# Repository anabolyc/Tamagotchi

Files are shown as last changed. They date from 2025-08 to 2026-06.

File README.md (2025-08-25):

# ArduinoGotchi - A real Tamagotchi emulator for Arduino UNO

## Synopsis

**ArduinoGotchi** is a real [Tamagotchi P1](https://tamagotchi.fandom.com/wiki/Tamagotchi_(1996_Pet)) emulator running in Arduino UNO hardware. The emulation core is based on [TamaLib](https://github.com/jcrona/tamalib) with intensive optimization to make it fit into UNO's hardware that only comes with 32K Flash 2K RAM.

Tamagotchi P1 Actual Devices

## Fork notice

I did the following changes after forking [original repo](https://github.com/GaryZ88/ArduinoGotchi)
- Created a platformio project, so it is easy to target multiple platforms
- Created ports for ESP8266 and ESP32, mainly because the speed on 8-bit AVR is just too slow
- Added long click on "back" button - if you press it for 5 seconds, it will reset memory back to egg state
- Added inverted Speaker connection setting. Mainly because the Piezo modules that I have are active on Low. Another reason is mentioned below.

I personally assembled the ESP8266 version with Wemos D1 Mini on a perf board, using the built-in LED together with a speaker, so when it sounds, the LED is blinking as well.

### Demo
Demo #1
Demo #2
Demo #3

## How to build and run

Use Platformio. Run the `build` task to build for all platforms. Next, run the `Upload` task for a specific platform

### Additional notes
- To activate your pet, you have to configure the clock by pressing the middle button. Otherwise, your pet will not be alive.
- The emulator will save the game status every 5 minutes. You can change that by changing the AUTO_SAVE_MINUTES setting
- The speed of the emulator is a bit slower than the actual Tamagotchi device on AVR; still, it is fun. On ESPs, it runs smoothly.
- There are a few costs in the `platformio.ini` that you can adjust to fit your needs:
```
  -D DISPLAY_I2C_ADDRESS=0x3C
  -D SCREEN_WIDTH=128
  -D SCREEN_HEIGHT=64
  -D ENABLE_TAMA_SOUND
  -D ENABLE_TAMA_SOUND_ACTIVE_LOW
  -D ENABLE_AUTO_SAVE_STATUS
  -D ENABLE_LOAD_STATE_FROM_EEPROM
```

### Board revisions

#### Revision A

The first prototype used an external boost converter module soldered on the PCB for simplicity. However boost converter I used would give up too early, not pulling all the juice from the battery.
This version contained one schematic issue: GPIO2 used for the buzzer caused boot issues (bootstrap pin)



#### Revision B

Switched over to on-board boost converter (TPS61040DBVR). Buzzer pin changed to IO0.



#### Revision C

Identical electrically to rev B, however, I switched to onboard SMD buttons (soldered from the factory), as they had much better feel compared to the through-hole buttons I used before. 



#### Revision D

Switched to XC9140A331MR boost converter, as this one can run down to 0.9V before it dies out. Added onboard power switch, so it can be switched off without removing batteries. Switched to onboard buzzer I used in another project to make the bottom line flat (that way it can be placed on the desk, for example). 

Also, I decided to switch to ESP32-S2 from ESP8266 as they become more and more available. Also I had a bunch of them, and I didn't really know where to use them ;)



### License
ArduinoGotchi is distributed under the GPLv2 license. See the LICENSE file for more information.

### Where to buy

You may support my work by ordering the kit on [Tindie](https://www.tindie.com/products/sonocotta/esp8266-tamagotchi-diy-kit/) or [Elecrow](https://www.elecrow.com/esp8266-tamagotchi-diy-kit.html)

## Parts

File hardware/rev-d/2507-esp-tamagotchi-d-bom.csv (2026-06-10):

ID | Name | Designator | Footprint | Quantity | Manufacturer Part | Manufacturer | Supplier | Supplier Part | Price
1 | BH-AAA-B5AK001 | BT1 | BAT-SMD_BH-AAA-B5AA001 | 1 | BH-AAA-B5AK001 | MYOUNG(美阳) | LCSC | C964882 | 1.188
2 | SSSS811101 | SW5 | SW-SMD_SSSS811101 | 1 | SSSS811101 | ALPSALPINE(阿尔卑斯阿尔派) | LCSC | C109335 | 0.147
3 | 2700Hz | BUZZER2 | BUZ-SMD_4P-L8.5-W8.5-P8.50-BR | 1 | MLT-8530 | 华能 | LCSC | C94599 | 0.208
4 | 10uF | C3,C10 | C0805 | 2 | CL21A106KAYNNNE | SAMSUNG | LCSC | C15850 | 0.048
5 | 4.7uH | L1 | IND-SMD_L4.0-W4.0 | 1 | YNR4018-4R7M | YJYCOIN(益嘉源) | LCSC | C340369 | 0.066
6 | 100nF | C13,C12 | C0402 | 2 | CL05B104KO5NNNC | SAMSUNG | LCSC | C1525 | 0.002
7 | 10uF | C15,C16 | CAP-SMD_L3.2-W1.6-RD-C7171 | 2 | TAJA106K016RNJ | Kyocera AVX | LCSC | C7171 | 0.15
8 | XC9140A331MR-G | U6 | SOT-23-5_L2.9-W1.6-P0.94-LS2.8-BL | 1 | XC9140A331MR-G | TOREX(特瑞仕) | LCSC | C484298 | 0.644
9 | MIDDLE | SW1 | KEY-SMD_2P-L6.0-W6.0-P6.00 | 1 | SKPMBJE010 | ALPSALPINE(阿尔卑斯阿尔派) | LCSC | C842853 | 0.162
10 | RIGHT | SW2 | KEY-SMD_2P-L6.0-W6.0-P6.00 | 1 | SKPMBJE010 | ALPSALPINE(阿尔卑斯阿尔派) | LCSC | C842853 | 0.162
11 | LEFT | SW3 | KEY-SMD_2P-L6.0-W6.0-P6.00 | 1 | SKPMBJE010 | ALPSALPINE(阿尔卑斯阿尔派) | LCSC | C842853 | 0.162
12 | 10kΩ | R6,R7,R8 | R0805 | 3 | 0805W8F1002T5E | UNI-ROYAL(厚声) | LCSC | C17414 | 0.003

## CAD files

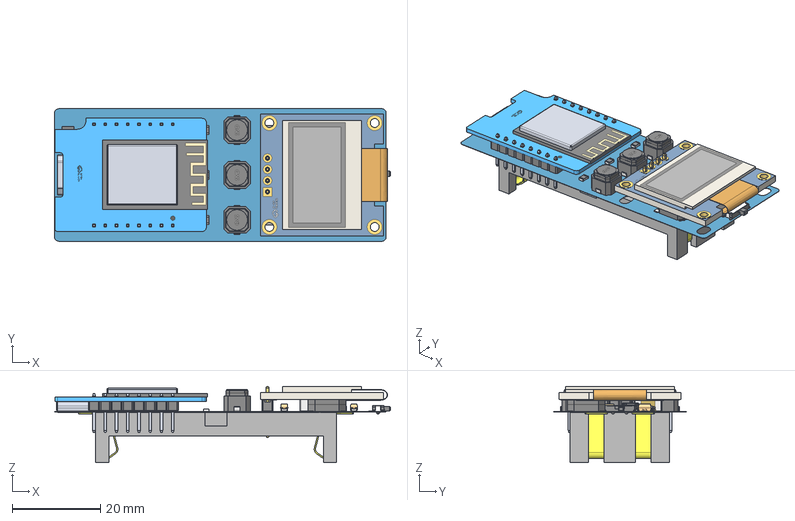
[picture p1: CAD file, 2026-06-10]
hardware/rev-d/2304-esp-tamagotchi-d-step.step
75.9 x 30.0 x 17.2 mm
Board~Su5C
TopCopper~Su5C
BottomCopper~Su5C
TopSilkscreen~Su5C
BottomSilkscreen~Su5C
TopFpcStiffener~Su5C
BottomFpcStiffener~Su5C
C0805~C0805_L2.0-W1.3-H1.3~YBXs x 2
C0402~C0402_L1.0-W0.5-H0.5~pOAQ x 2
IND-SMD_L4.0-W4.0~IND-SMD_L4.0-W4.0-H1.9~UKnZ
CAP-SMD_L3.2-W1.6-RD-C7171~CASE-A_L3.2-W1.6-H1.6~hhSS x 2
BUZ-SMD_4P-L8.5-W8.5-P8.50-BR~BUZ-SMD_4P-L8.5-W8.5-H4.0~ux79
SW-SMD_SSSS811101~SW-TH_SSSS811101~p5gn
R0805~R0805_L2.0-W1.3-H0.6~nQuS x 3
BAT-SMD_BH-AAA-B5AA001~BAT-SMD_BH-AAA-B5AA001~pLz2
KEY-SMD_2P-L6.0-W6.0-P6.00~KEY-SMD_2P-L6.0-W6.0-H5.0-P6.00~R7So x 3
SOT-23-5_L2.9-W1.6-P0.94-LS2.8-BL~SOT-23-5_L2.9-W1.6-P0.94-LS2.8-BL~vnJl
WEMOS D1 MINI~DIP-16_WEMOS_D1_MINI_PRO4~re9i
0.96-OLED-DISPLAY~TH-4_SSD1306~hwig

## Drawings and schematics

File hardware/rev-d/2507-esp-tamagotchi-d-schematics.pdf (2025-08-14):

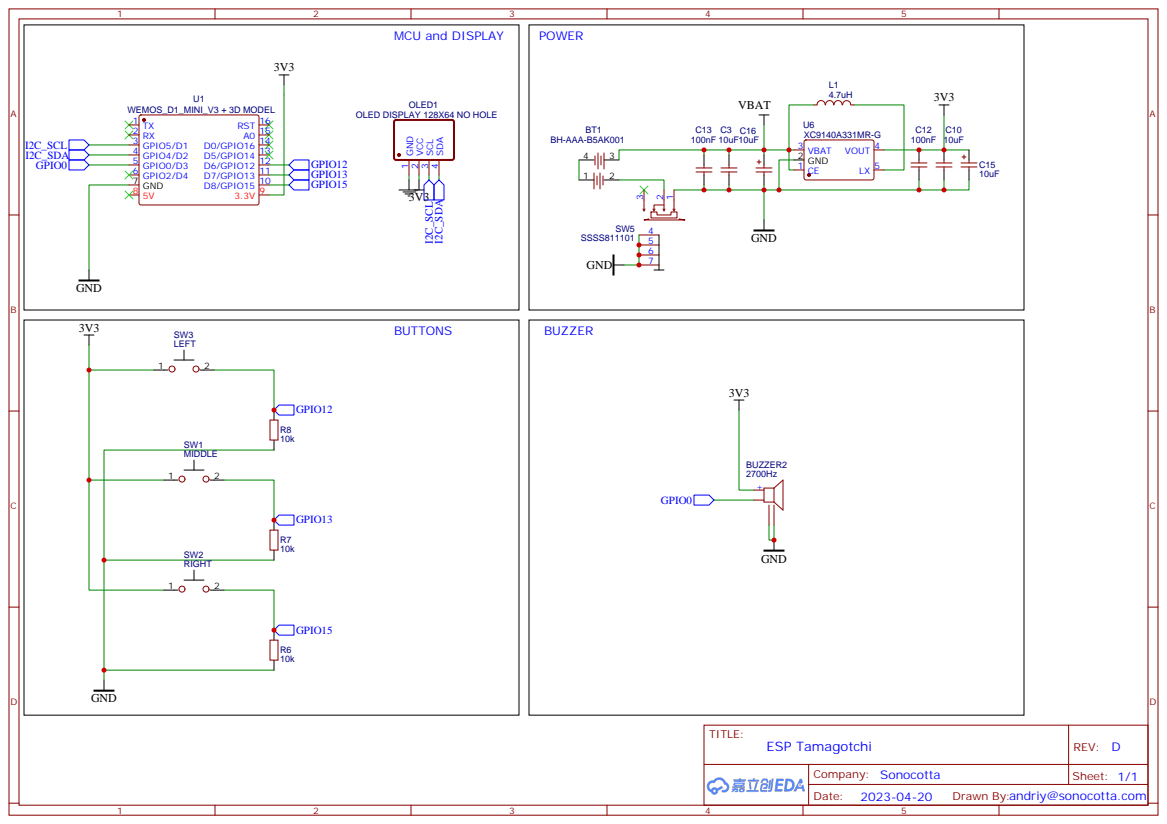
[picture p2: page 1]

OLED DISPLAY 128X64 NO HOLE

Drawn By:andriy@sonocotta.com

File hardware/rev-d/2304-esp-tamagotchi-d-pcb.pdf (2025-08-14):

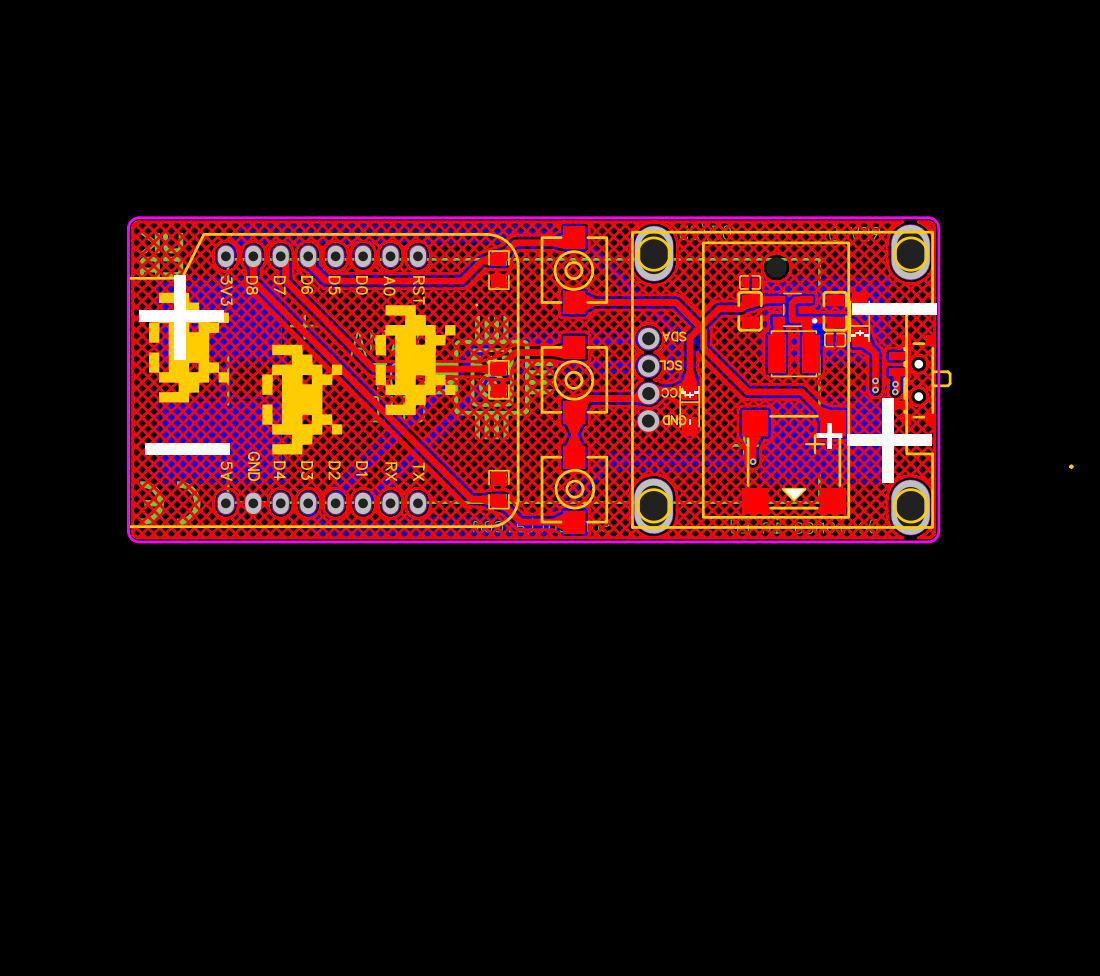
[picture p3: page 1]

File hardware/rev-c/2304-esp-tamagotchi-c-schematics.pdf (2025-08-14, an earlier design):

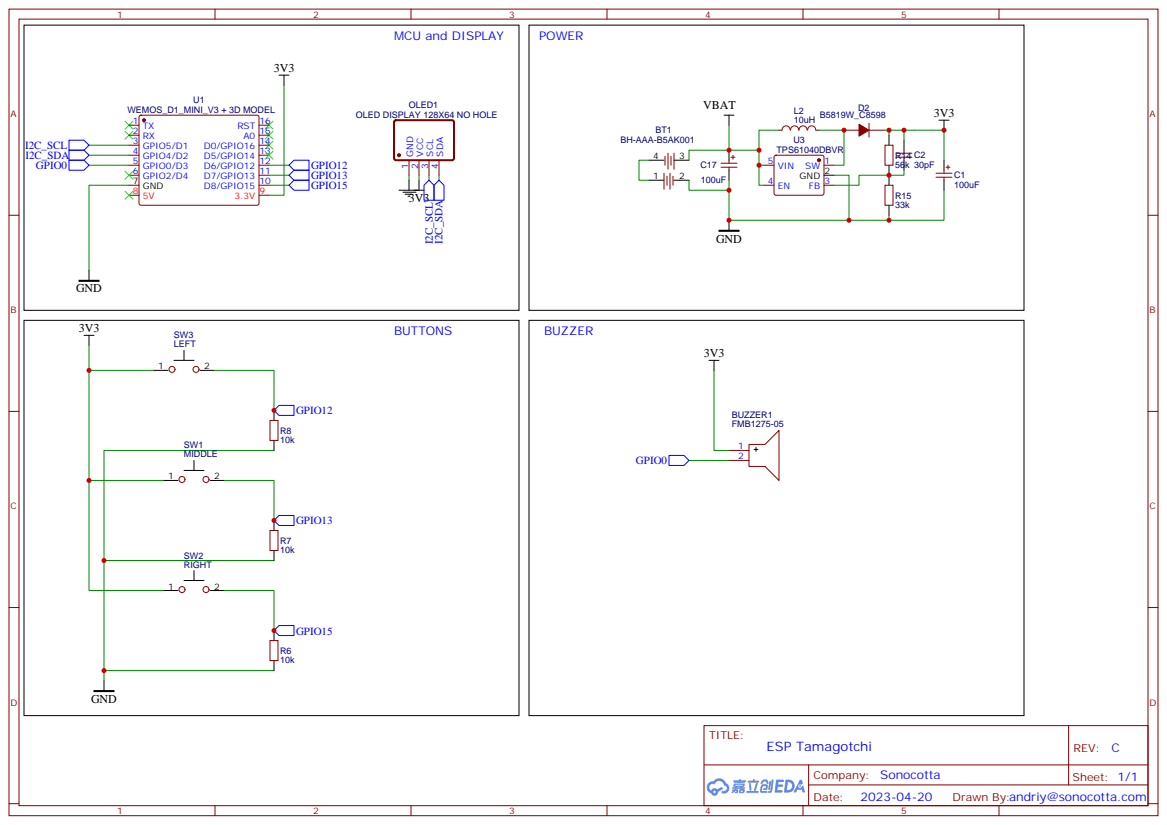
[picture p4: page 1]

OLED DISPLAY 128X64 NO HOLE

Drawn By:andriy@sonocotta.com

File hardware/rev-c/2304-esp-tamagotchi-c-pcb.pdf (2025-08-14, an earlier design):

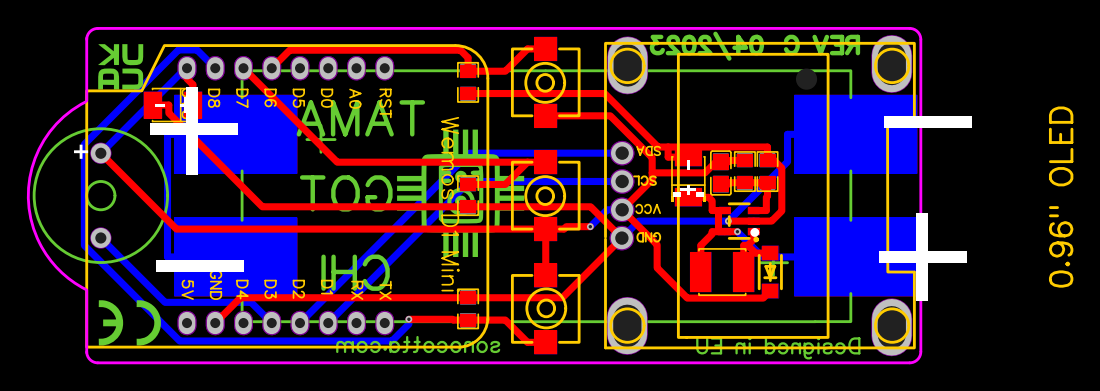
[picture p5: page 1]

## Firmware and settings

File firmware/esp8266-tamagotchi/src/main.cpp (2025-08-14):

/*
 * ArduinoGotchi - A real Tamagotchi emulator for Arduino UNO
 *
 * Copyright (C) 2022 Gary Kwok
 *
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
 * You should have received a copy of the GNU General Public License
 * along with this program; if not, write to the Free Software
 * Foundation, Inc., 51 Franklin Street, Fifth Floor, Boston, MA  02110-1301, USA.
 */

#include <U8g2lib.h>
#include <Wire.h>

#include "tamalib.h"
#include "hw.h"
#include "bitmaps.h"
#include "savestate.h"

/***** Set display orientation, U8G2_MIRROR_VERTICAL is not supported *****/
//#define U8G2_LAYOUT_NORMAL
#define U8G2_LAYOUT_ROTATE_180
//#define U8G2_LAYOUT_MIRROR
/**************************************************************************/

#if defined(PIN_I2C_SDA) && defined(PIN_I2C_SCL) 
#ifdef U8G2_LAYOUT_NORMAL
U8G2_SSD1306_128X64_NONAME_2_HW_I2C display(U8G2_R0, U8X8_PIN_NONE, PIN_I2C_SCL, PIN_I2C_SDA);
#endif
#ifdef U8G2_LAYOUT_ROTATE_180
U8G2_SSD1306_128X64_NONAME_2_HW_I2C display(U8G2_R2, U8X8_PIN_NONE, PIN_I2C_SCL, PIN_I2C_SDA);
#endif
#ifdef U8G2_LAYOUT_MIRROR
U8G2_SSD1306_128X64_NONAME_2_HW_I2C display(U8G2_MIRROR, U8X8_PIN_NONE, PIN_I2C_SCL, PIN_I2C_SDA);
#endif
#else
#ifdef U8G2_LAYOUT_NORMAL
U8G2_SSD1306_128X64_NONAME_2_HW_I2C display(U8G2_R0);
#endif
#ifdef U8G2_LAYOUT_ROTATE_180
U8G2_SSD1306_128X64_NONAME_2_HW_I2C display(U8G2_R2);
#endif
#ifdef U8G2_LAYOUT_MIRROR
U8G2_SSD1306_128X64_NONAME_2_HW_I2C display(U8G2_MIRROR);
#endif
#endif

void displayTama();

/**** TamaLib Specific Variables ****/
static uint16_t current_freq = 0;
static bool_t matrix_buffer[LCD_HEIGHT][LCD_WIDTH / 8] = {{0}};
//static byte runOnceBool = 0;
static bool_t icon_buffer[ICON_NUM] = {0};
static cpu_state_t cpuState;
static unsigned long lastSaveTimestamp = 0;
/************************************/

static void hal_halt(void)
{
  // Serial.println("Halt!");
}

static void hal_log(log_level_t level, char *buff, ...)
{
  Serial.println(buff);
}

static void hal_sleep_until(timestamp_t ts)
{
  // int32_t remaining = (int32_t) (ts - hal_get_timestamp());
  // if (remaining > 0) {
  // delayMicroseconds(1);
  // delay(1);
  //}
}

static timestamp_t hal_get_timestamp(void)
{
  return millis() * 1000;
}

static void hal_update_screen(void)
{
  displayTama();
}

static void hal_set_lcd_matrix(u8_t x, u8_t y, bool_t val)
{
  uint8_t mask;
  if (val)
  {
    mask = 0b10000000 >> (x % 8);
    matrix_buffer[y][x / 8] = matrix_buffer[y][x / 8] | mask;
  }
  else
  {
    mask = 0b01111111;
    for (byte i = 0; i < (x % 8); i++)
    {
      mask = (mask >> 1) | 0b10000000;
    }
    matrix_buffer[y][x / 8] = matrix_buffer[y][x / 8] & mask;
  }
}

static void hal_set_lcd_icon(u8_t icon, bool_t val)
{
  icon_buffer[icon] = val;
}

static void hal_set_frequency(u32_t freq)
{
  current_freq = freq;
}

static void hal_play_frequency(bool_t en)
{
#ifdef ENABLE_TAMA_SOUND
  if (en)
  {
    tone(PIN_BUZZER, current_freq);
  }
  else
  {
    noTone(PIN_BUZZER);
    #ifdef ENABLE_TAMA_SOUND_ACTIVE_LOW
    digitalWrite(PIN_BUZZER, HIGH);
    #endif
  }
#endif
}

static int hal_handler(void)
{
#ifdef ENABLE_SERIAL_DEBUG_INPUT
  if (Serial.available() > 0)
  {
    int incomingByte = Serial.read();
    Serial.println(incomingByte, DEC);
    if (incomingByte == 49)
    {
      hw_set_button(BTN_LEFT, BTN_STATE_PRESSED);
    }
    else if (incomingByte == 50)
    {
      hw_set_button(BTN_LEFT, BTN_STATE_RELEASED);
    }
    else if (incomingByte == 51)
    {
      hw_set_button(BTN_MIDDLE, BTN_STATE_PRESSED);
    }
    else if (incomingByte == 52)
    {
      hw_set_button(BTN_MIDDLE, BTN_STATE_RELEASED);
    }
    else if (incomingByte == 53)
    {
      hw_set_button(BTN_RIGHT, BTN_STATE_PRESSED);
    }
    else if (incomingByte == 54)
    {
      hw_set_button(BTN_RIGHT, BTN_STATE_RELEASED);
    }
  }
#else
  if (digitalRead(PIN_BTN_L) == HIGH)
  {
    hw_set_button(BTN_LEFT, BTN_STATE_PRESSED);
  }
  else
  {
    hw_set_button(BTN_LEFT, BTN_STATE_RELEASED);
  }
  if (digitalRead(PIN_BTN_M) == HIGH)
  {
    hw_set_button(BTN_MIDDLE, BTN_STATE_PRESSED);
  }
  else
  {
    hw_set_button(BTN_MIDDLE, BTN_STATE_RELEASED);
  }
  if (digitalRead(PIN_BTN_R) == HIGH)
  {
    hw_set_button(BTN_RIGHT, BTN_STATE_PRESSED);
  }
  else
  {
    hw_set_button(BTN_RIGHT, BTN_STATE_RELEASED);
  }
// #ifdef ENABLE_AUTO_SAVE_STATUS
//   static bool_t button4state = 0;
//   if (digitalRead(PIN_BTN_SAVE) == HIGH)
//   {
//     if (button4state == 0)
//     {
//       saveStateToEEPROM(&cpuState);
//     }
//     button4state = 1;
//   }
//   else
//   {
//     button4state = 0;
//   }
// #endif
#endif
  return 0;
}

static hal_t hal = {
    .halt = &hal_halt,
    .log = &hal_log,
    .sleep_until = &hal_sleep_until,
    .get_timestamp = &hal_get_timestamp,
    .update_screen = &hal_update_screen,
    .set_lcd_matrix = &hal_set_lcd_matrix,
    .set_lcd_icon = &hal_set_lcd_icon,
    .set_frequency = &hal_set_frequency,
    .play_frequency = &hal_play_frequency,
    .handler = &hal_handler,
};

void drawTriangle(uint8_t x, uint8_t y)
{
  // display.drawLine(x,y,x+6,y);
  display.drawLine(x + 1, y + 1, x + 5, y + 1);
  display.drawLine(x + 2, y + 2, x + 4, y + 2);
  display.drawLine(x + 3, y + 3, x + 3, y + 3);
}

void drawTamaRow(uint8_t tamaLCD_y, uint8_t ActualLCD_y, uint8_t thick)
{
  uint8_t i;
  for (i = 0; i < LCD_WIDTH; i++)
  {
    uint8_t mask = 0b10000000;
    mask = mask >> (i % 8);
    if ((matrix_buffer[tamaLCD_y][i / 8] & mask) != 0)
    {
      display.drawBox(i + i + i + 16, ActualLCD_y, 2, thick);
    }
  }
}

void drawTamaSelection(uint8_t y)
{
  uint8_t i;
  for (i = 0; i < 7; i++)
  {
    if (icon_buffer[i])
      drawTriangle(i * 16 + 5, y);
    display.drawXBMP(i * 16 + 4, y + 6, 16, 9, bitmaps + i * 18);
  }
  if (icon_buffer[7])
  {
    drawTriangle(7 * 16 + 5, y);
    display.drawXBMP(7 * 16 + 4, y + 6, 16, 9, bitmaps + 7 * 18);
  }
}

void displayTama()
{
  uint8_t j;
  display.firstPage();
#ifdef U8G2_LAYOUT_ROTATE_180
  drawTamaSelection(49);
  display.nextPage();

  for (j = 11; j < LCD_HEIGHT; j++)
  {
    drawTamaRow(j, j + j + j, 2);
  }
  display.nextPage();

  for (j = 5; j <= 10; j++)
  {
    if (j == 5)
    {
      drawTamaRow(j, j + j + j + 1, 1);
    }
    else
    {
      drawTamaRow(j, j + j + j, 2);
    }
  }
  display.nextPage();

  for (j = 0; j <= 5; j++)
  {
    if (j == 5)
    {
      drawTamaRow(j, j + j + j, 1);
    }
    else
    {
      drawTamaRow(j, j + j + j, 2);
    }
  }
  display.nextPage();
#else
  for (j = 0; j < LCD_HEIGHT; j++)
  {
    if (j != 5)
      drawTamaRow(j, j + j + j, 2);
    if (j == 5)
    {
      drawTamaRow(j, j + j + j, 1);
      display.nextPage();
      drawTamaRow(j, j + j + j + 1, 1);
    }
    if (j == 10)
      display.nextPage();
  }
  display.nextPage();
  drawTamaSelection(49);
  display.nextPage();
#endif
}

#ifdef ENABLE_DUMP_STATE_TO_SERIAL_WHEN_START
void dumpStateToSerial()
{
  uint16_t i, count = 0;
  char tmp[10];
  cpu_get_state(&cpuState);
  u4_t *memTemp = cpuState.memory;
  uint8_t *cpuS = (uint8_t *)&cpuState;

  Serial.println("");
  Serial.println("static const uint8_t hardcodedState[] PROGMEM = {");
  for (i = 0; i < sizeof(cpu_state_t); i++, count++)
  {
    sprintf(tmp, "0x%02X,", cpuS[i]);
    Serial.print(tmp);
    if ((count % 16) == 15)
      Serial.println("");
  }
  for (i = 0; i < MEMORY_SIZE; i++, count++)
  {
    sprintf(tmp, "0x%02X,", memTemp[i]);
    Serial.print(tmp);
    if ((count % 16) == 15)
      Serial.println("");
  }
  Serial.println("};");
  /*
    Serial.println("");
    Serial.println("static const uint8_t bitmaps[] PROGMEM = {");
    for(i=0;i<144;i++) {
      sprintf(tmp, "0x%02X,", bitmaps_raw[i]);
      Serial.print(tmp);
      if ((i % 18)==17) Serial.println("");
    }
    Serial.println("};");  */
}
#endif

uint8_t reverseBits(uint8_t num)
{
  uint8_t reverse_num = 0;
  uint8_t i;
  for (i = 0; i < 8; i++)
  {
    if ((num & (1 << i)))
      reverse_num |= 1 << ((8 - 1) - i);
  }
  return reverse_num;
}

void setup()
{
  Serial.begin(SERIAL_BAUD);
  Serial.println(F("\nStarting Tamagotchi..."));

  pinMode(PIN_BTN_L, INPUT);
  pinMode(PIN_BTN_M, INPUT);
  pinMode(PIN_BTN_R, INPUT);
  pinMode(PIN_BUZZER, OUTPUT);

  Serial.println(F("Initializing display..."));
  display.begin();

  tamalib_register_hal(&hal);
  tamalib_set_framerate(TAMA_DISPLAY_FRAMERATE);
  tamalib_init(1000000);

  initEEPROM();

#ifdef ENABLE_LOAD_STATE_FROM_EEPROM
  if (validEEPROM())
  {
    loadStateFromEEPROM(&cpuState);
  } else {
    Serial.println(F("No magic number in state, skipping state restore"));
  }
#elif ENABLE_LOAD_HARCODED_STATE_WHEN_START
  loadHardcodedState();
#endif

#ifdef ENABLE_DUMP_STATE_TO_SERIAL_WHEN_START
  dumpStateToSerial();
#endif
  Serial.println(F("Tamagotchi initialized."));
}

uint32_t right_long_press_started = 0;

void loop()
{
  tamalib_mainloop_step_by_step();
#ifdef ENABLE_AUTO_SAVE_STATUS
  if ((millis() - lastSaveTimestamp) > (AUTO_SAVE_MINUTES * 60 * 1000))
  {
    lastSaveTimestamp = millis();
    saveStateToEEPROM(&cpuState);
  }

  if (digitalRead(PIN_BTN_M) == HIGH) {
    if (millis() - right_long_press_started > AUTO_SAVE_MINUTES * 1000) 
    {
      eraseStateFromEEPROM();
      #if defined(ESP8266) || defined(ESP32)
      ESP.restart();
      #endif
    }
  } else {
    right_long_press_started = millis();
  }
#endif
}

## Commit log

2025-08-14 Features/rev d board (#2)
    * Upd configs
    * Added hardware files
    * Added hw files
    * Fixed build warnings
    * Update README.md
    ---------
    [main.cpp]
2026-06-10 Added latet production files and 3d model file
    [2304-esp-tamagotchi-d-pick-and-place.csv, 2304-esp-tamagotchi-d-step.step, 2507-esp-tamagotchi-d-bom.csv]

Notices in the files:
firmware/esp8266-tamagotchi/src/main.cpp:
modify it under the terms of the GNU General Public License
